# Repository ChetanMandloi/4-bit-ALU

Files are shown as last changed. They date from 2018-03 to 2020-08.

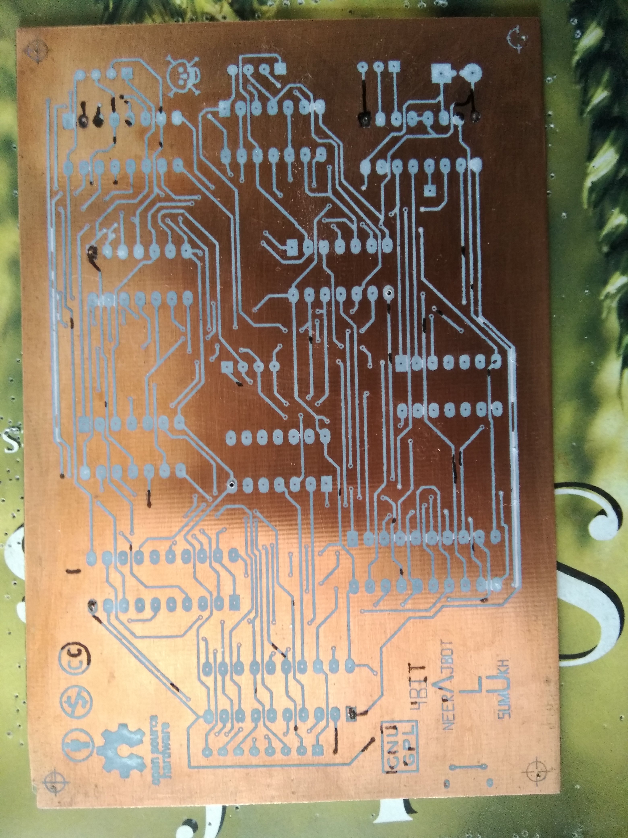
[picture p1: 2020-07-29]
Pictures of Construction/Ink Transfer on Base Module - Bottom Layer.jpg

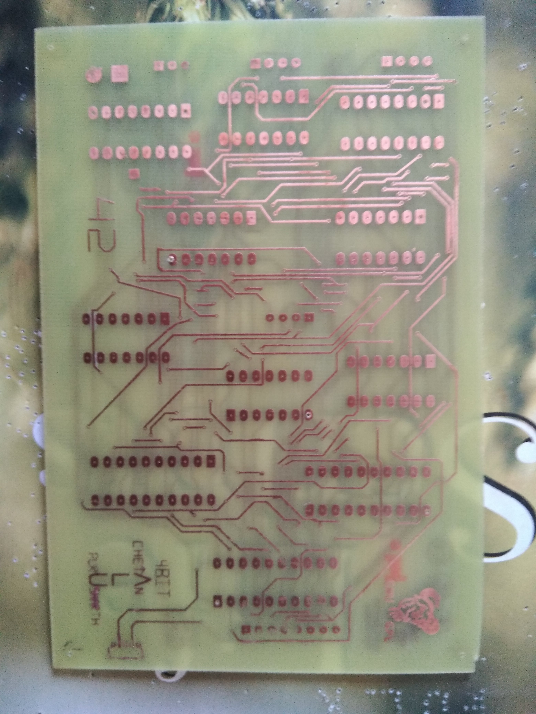
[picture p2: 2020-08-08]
Pictures of Construction/Etched Base Module - Top Layer.jpg

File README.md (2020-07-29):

# 4-bit-ALU
A simple design to perform basic logical operations (such as logical AND, OR, NOT, Addition, Subtraction and Multiplication) on two 4 bit variables using DIY PCB fabrication and assembly methods.

KiCad files to allow you to make a 4 bit ALU using Double sided copper clad board.
Pictures and instructions incoming soon.

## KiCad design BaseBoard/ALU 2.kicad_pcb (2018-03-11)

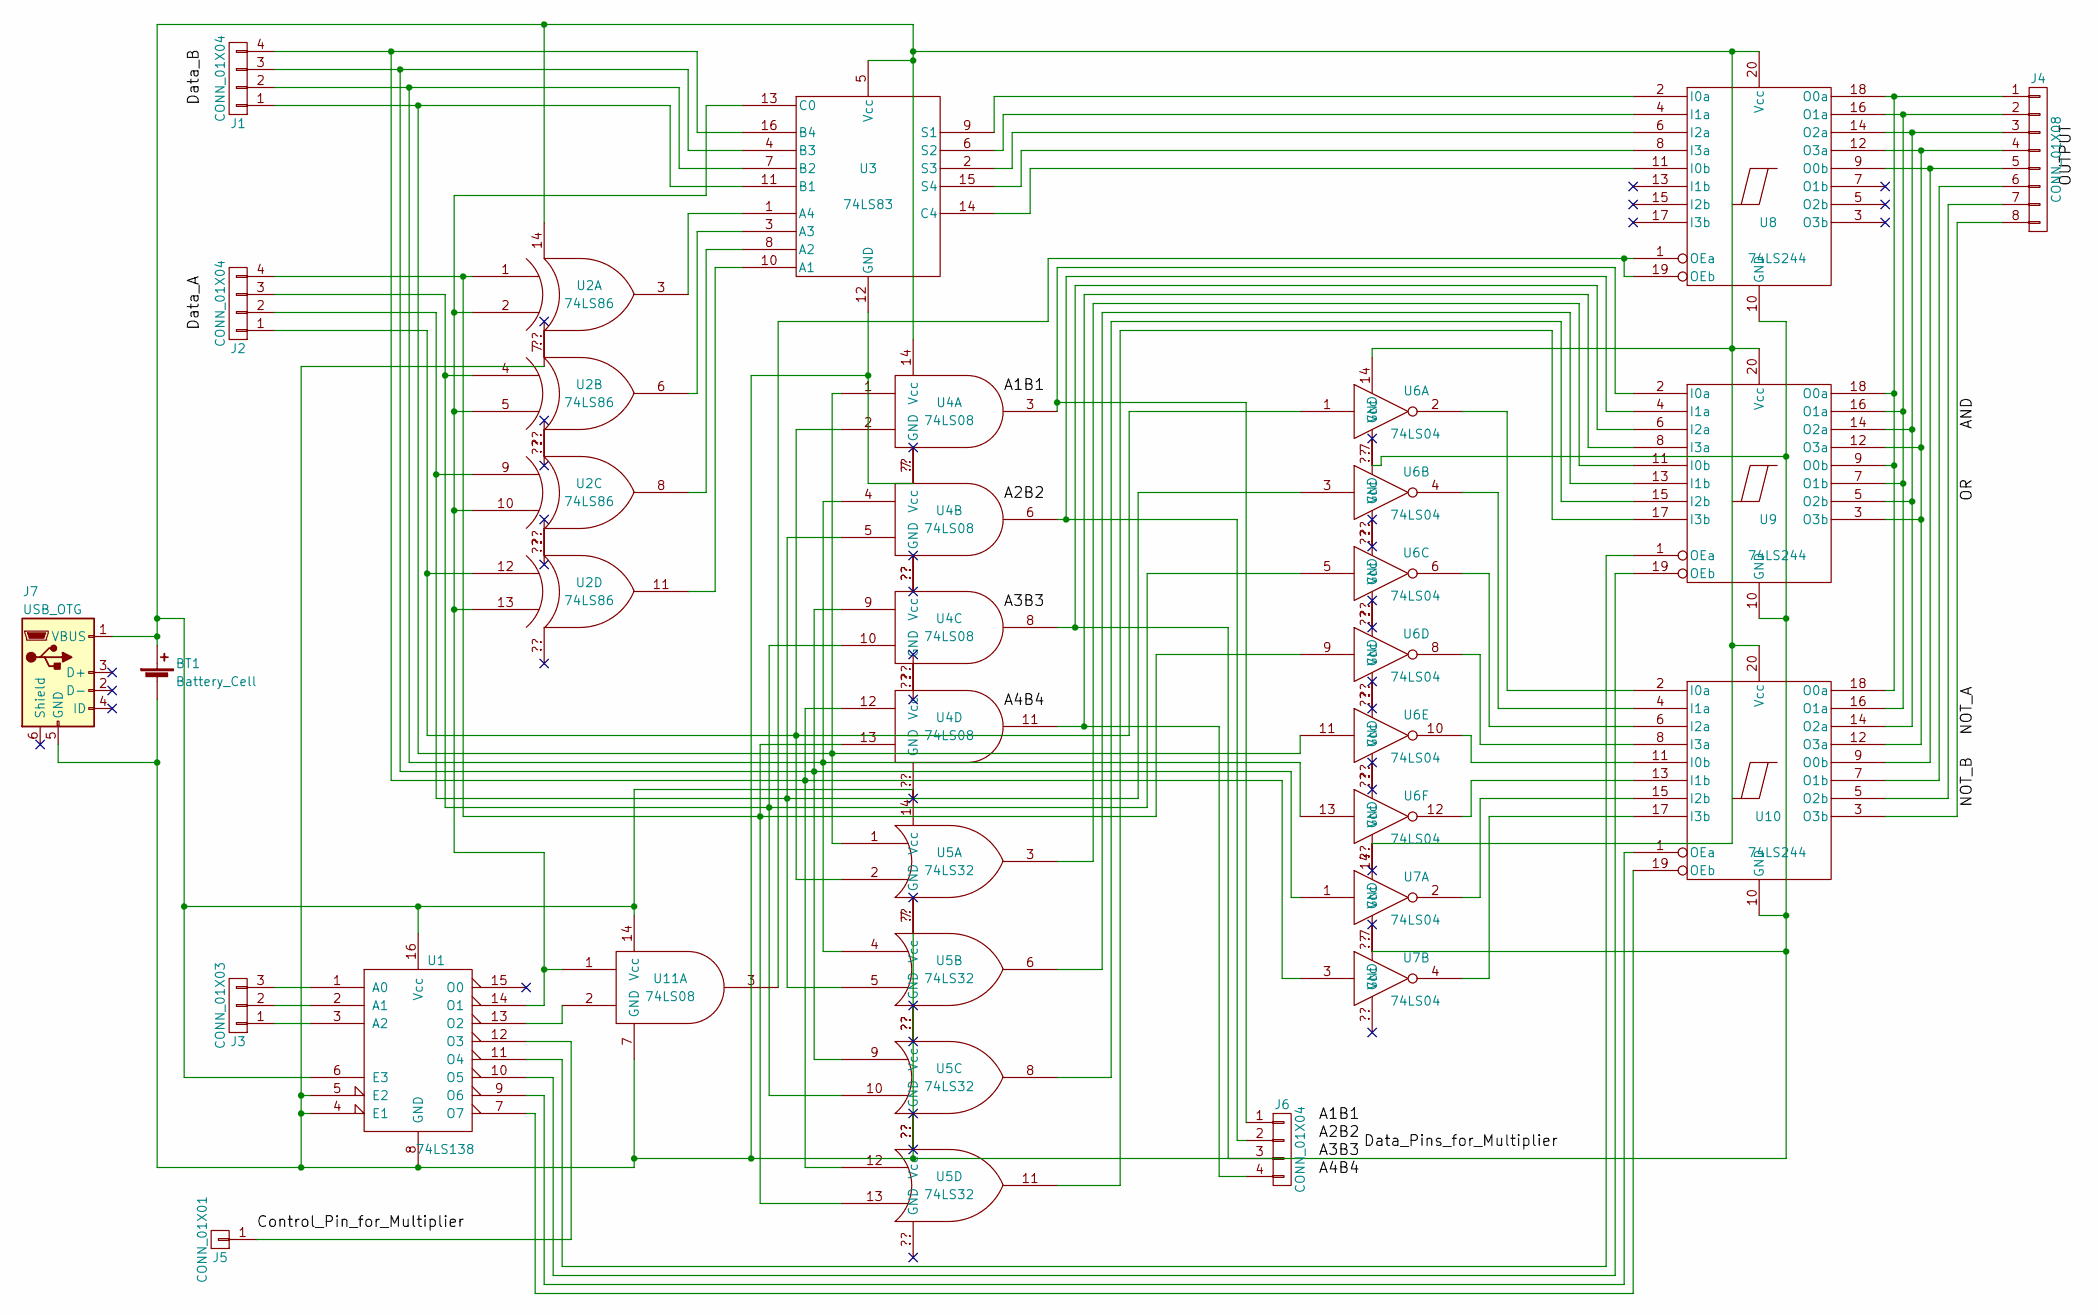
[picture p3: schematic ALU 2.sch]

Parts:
BT1: Battery_Cell; bornier2
J1, J2, J6: CONN_01X04; Pin_Header_Straight_1x04_Pitch2.54mm
J3: CONN_01X03; Pin_Header_Straight_1x03_Pitch2.54mm
J4: CONN_01X08; Pin_Header_Straight_1x08_Pitch2.54mm
J5: CONN_01X01; Pin_Header_Straight_1x01_Pitch2.54mm
J7: USB_OTG; USB_Micro-B
U1: 74LS138; DIP-16_W7.62mm_Socket_LongPads
U2: 74LS86; DIP-14_W7.62mm_Socket_LongPads
U3: 74LS83; DIP-16_W7.62mm_Socket_LongPads
U4, U11: 74LS08; DIP-14_W7.62mm_Socket_LongPads
U5: 74LS32; DIP-14_W7.62mm_Socket_LongPads
U6, U7: 74LS04; DIP-14_W7.62mm_Socket_LongPads
U8, U9, U10: 74LS244; DIP-20_W7.62mm_Socket_LongPads

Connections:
/A2B2: BT1.2 (-), J7.5 (GND), U1.4 (E1), U1.5 (E2), U1.8 (GND), U2.7 (GND), U3.12 (GND), U4.7 (GND), U5.7 (GND), U6.7 (GND), U7.7 (GND), U8.10 (GND), U9.10 (GND), U10.10 (GND), U11.7 (GND)
unnamed: BT1.1 (+), J7.1 (VBUS), U1.6 (E3), U1.16 (Vcc), U2.14 (Vcc), U3.5 (Vcc), U4.14 (Vcc), U5.14 (Vcc), U6.14 (Vcc), U7.14 (Vcc), U8.20 (Vcc), U9.20 (Vcc), U10.20 (Vcc), U11.14 (Vcc)
unnamed: J1.1, U3.11 (B1), U4.1, U5.1, U6.11
unnamed: J1.2, U3.7 (B2), U4.4, U5.4, U6.13
unnamed: J1.3, U3.4 (B3), U4.9, U5.9, U7.1
unnamed: J1.4, U3.16 (B4), U4.12, U5.12, U7.3
unnamed: J2.1, U2.12 (IN1), U4.2, U5.2, U6.1
unnamed: J2.2, U2.9 (IN1), U4.5, U5.5, U6.3
unnamed: J2.3, U2.4 (IN1), U4.10, U5.10, U6.5
unnamed: J2.4, U2.1 (IN1), U4.13, U5.13, U6.9
unnamed: J3.1, U1.3 (A2)
unnamed: J3.2, U1.2 (A1)
unnamed: J3.3, U1.1 (A0)
unnamed: J4.1, U8.18 (O0a), U9.9 (O0b), U9.18 (O0a), U10.18 (O0a)
unnamed: J4.2, U8.16 (O1a), U9.7 (O1b), U9.16 (O1a), U10.16 (O1a)
unnamed: J4.3, U8.14 (O2a), U9.5 (O2b), U9.14 (O2a), U10.14 (O2a)
unnamed: J4.4, U8.12 (O3a), U9.3 (O3b), U9.12 (O3a), U10.12 (O3a)
unnamed: J4.5, U8.9 (O0b), U10.9 (O0b)
unnamed: J4.6, U10.7 (O1b)
unnamed: J4.7, U10.5 (O2b)
unnamed: J4.8, U10.3 (O3b)
unnamed: J5.1, U1.12 (O3)
unnamed: J6.1, U4.3, U9.2 (I0a)
unnamed: J6.2, U4.6, U9.4 (I1a)
unnamed: J6.3, U4.8, U9.6 (I2a)
unnamed: J6.4, U4.11, U9.8 (I3a)
unnamed: U1.7 (O7), U10.19 (OEb)
unnamed: U1.9 (O6), U10.1 (OEa)
unnamed: U1.10 (O5), U9.19 (OEb)
unnamed: U1.11 (O4), U9.1 (OEa)
unnamed: U1.13 (O2), U11.2
unnamed: U1.14 (O1), U2.2 (IN2), U2.5 (IN2), U2.10 (IN2), U2.13 (IN2), U3.13 (C0), U11.1
unnamed: U2.3 (OUT), U3.1 (A4)
unnamed: U2.6 (OUT), U3.3 (A3)
unnamed: U2.8 (OUT), U3.8 (A2)
unnamed: U2.11 (OUT), U3.10 (A1)
unnamed: U3.2 (S3), U8.6 (I2a)
unnamed: U3.6 (S2), U8.4 (I1a)
unnamed: U3.9 (S1), U8.2 (I0a)
unnamed: U3.14 (C4), U8.11 (I0b)
unnamed: U3.15 (S4), U8.8 (I3a)
unnamed: U5.3, U9.11 (I0b)
unnamed: U5.6, U9.13 (I1b)
unnamed: U5.8, U9.15 (I2b)
unnamed: U5.11, U9.17 (I3b)
unnamed: U6.2, U10.2 (I0a)
unnamed: U6.4, U10.4 (I1a)
unnamed: U6.6, U10.6 (I2a)
unnamed: U6.8, U10.8 (I3a)
unnamed: U6.10, U10.11 (I0b)
unnamed: U6.12, U10.13 (I1b)
unnamed: U7.2, U10.15 (I2b)
unnamed: U7.4, U10.17 (I3b)
unnamed: U8.1 (OEa), U8.19 (OEb), U11.3

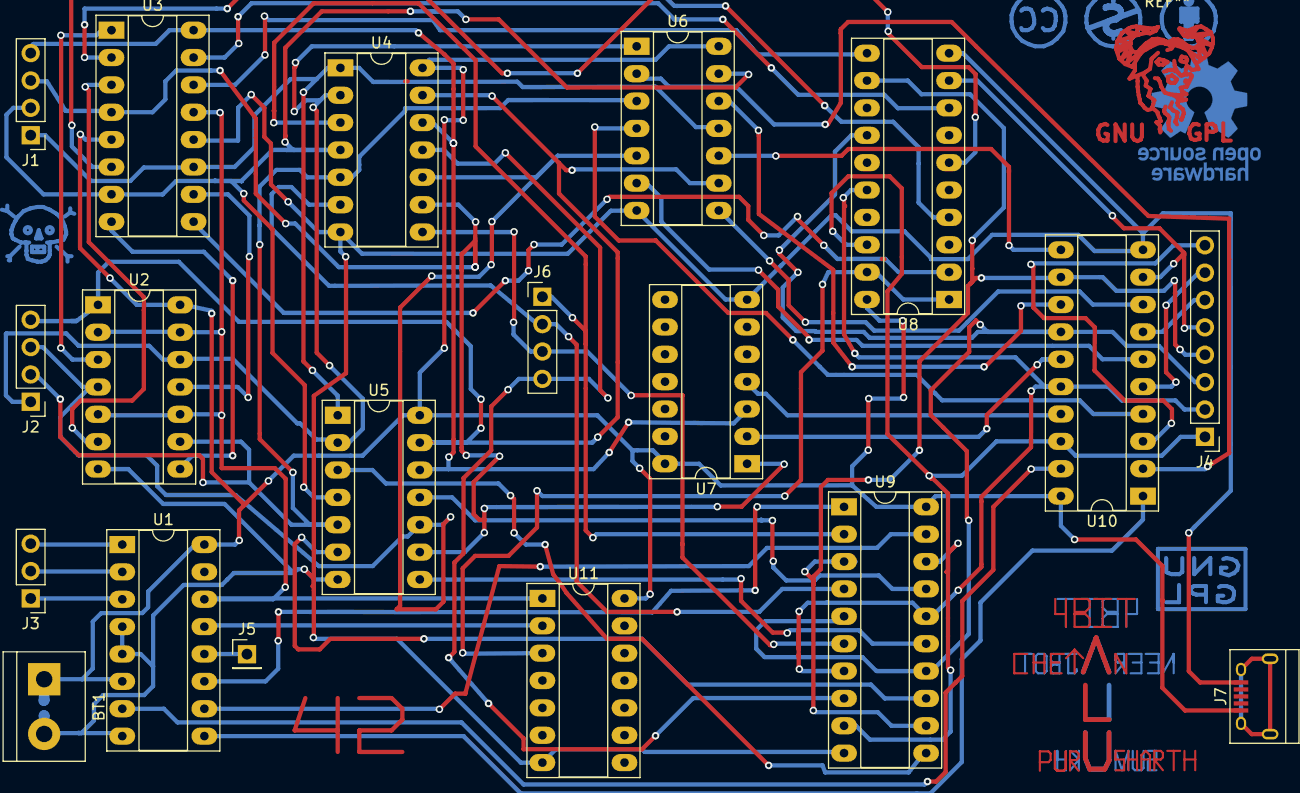
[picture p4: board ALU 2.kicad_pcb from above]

Board: 2 copper layers, 19 parts (0 on the bottom side), 54 nets.

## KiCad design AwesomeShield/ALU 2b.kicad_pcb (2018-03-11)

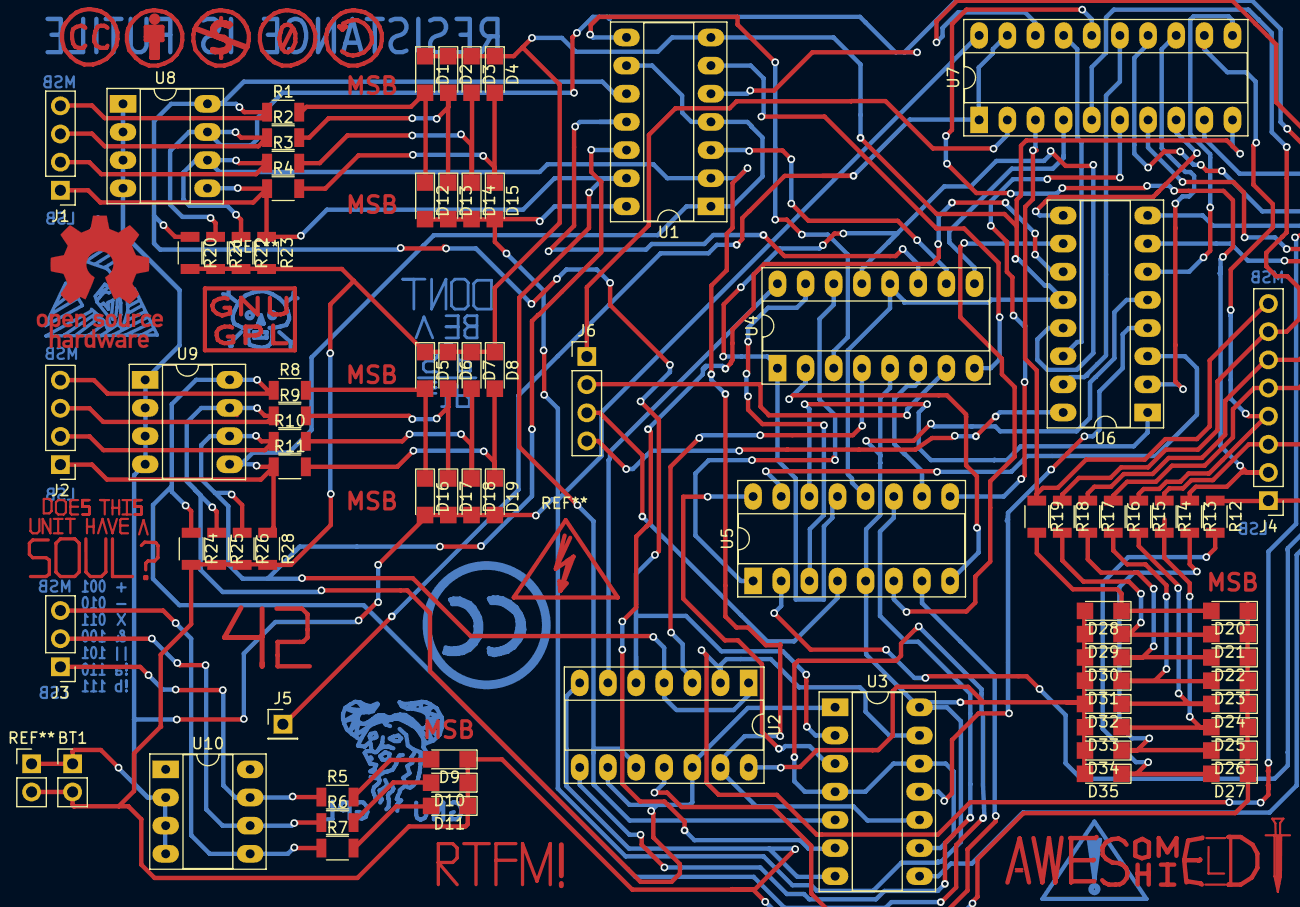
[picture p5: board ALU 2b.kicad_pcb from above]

Board: 2 copper layers, 79 parts (0 on the bottom side), 73 nets.

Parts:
BT1: Battery_Cell; Pin_Header_Straight_1x02_Pitch2.54mm
D1, D2, D3, D4, D5, D6, D7, D8, D9, D10, D11, D12, D13, D14, D15, D16, D17, D18, D19, D20, D21, D22, D23, D24, D25, D26, D27, D28, D29, D30, D31, D32, D33, D34, D35: LED; LED_1206
J1, J2, J6: CONN_01X04; Pin_Header_Straight_1x04_Pitch2.54mm
J3: CONN_01X03; Pin_Header_Straight_1x03_Pitch2.54mm
J4: CONN_01X08; Pin_Header_Straight_1x08_Pitch2.54mm
J5: CONN_01X01; Pin_Header_Straight_1x01_Pitch2.54mm
R1, R2, R3, R4, R5, R6, R7, R8, R9, R10, R11, R12, R13, R14, R15, R16, R17, R18, R19, R20, R21, R22, R23, R24, R25, R26, R28: R; R_1206
U1, U2, U3: 74LS08; DIP-14_W7.62mm_Socket_LongPads
U4, U5, U6: 74LS83; DIP-16_W7.62mm_Socket_LongPads
U7: 74LS244; DIP-20_W7.62mm_Socket_LongPads
U8, U9, U10: LM741; DIP-8_W7.62mm_Socket_LongPads

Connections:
/Control_Pin_from_Board_1: U6.15, U7.15
/Data_A: BT1.2, D1.1, D2.1, D3.1, D4.1, D5.1, D6.1, D7.1, D8.1, D9.1, D10.1, D11.1, D20.1, D21.1, D22.1, D23.1, D24.1, D25.1, D26.1, D27.1, R20.2, R21.2, R22.2, R23.2, R24.2, R25.2, R26.2, R28.2, U1.7, U2.7, U3.7, U4.12, U5.12, U6.12, U7.10
unnamed: BT1.1, D12.2, D13.2, D14.2, D15.2, D16.2, D17.2, D18.2, D19.2, D28.2, D29.2, D30.2, D31.2, D32.2, D33.2, D34.2, D35.2, U1.14, U2.14, U3.14, U4.5, U5.5, U6.5, U7.20, U8.1, U8.2, U8.3, U8.4, U9.1, U9.2, U9.3, U9.4, U10.2, U10.3, U10.4
unnamed: D1.2, D12.1, R1.2
unnamed: D9.2, R5.2
unnamed: D10.2, R6.2
unnamed: D11.2, R7.2
unnamed: D2.2, D13.1, R2.2
unnamed: D3.2, D14.1, R3.2
unnamed: D4.2, D15.1, R4.2
unnamed: D5.2, D16.1, R8.2
unnamed: D6.2, D17.1, R9.2
unnamed: D7.2, D18.1, R10.2
unnamed: D8.2, D19.1, R11.2
unnamed: D20.2, D28.1, R19.2
unnamed: D21.2, D29.1, R18.2
unnamed: D22.2, D30.1, R17.2
unnamed: D23.2, D31.1, R16.2
unnamed: D24.2, D32.1, R15.2
unnamed: D25.2, D33.1, R14.2
unnamed: D26.2, D34.1, R13.2
unnamed: D27.2, D35.1, R12.2
unnamed: J1.1, R4.1, R23.1, U1.13, U2.10, U3.5, U8.5
unnamed: J1.2, R3.1, R22.1, U1.2, U2.13, U3.10, U8.6
unnamed: J1.3, R2.1, R21.1, U1.5, U2.2, U3.13, U8.7
unnamed: J1.4, R1.1, R20.1, U1.10, U2.5, U3.2, U8.8
unnamed: J2.1, R11.1, R28.1, U1.1, U1.4, U1.9, U9.5
unnamed: J2.2, R10.1, R26.1, U1.12, U2.1, U2.4, U9.6
unnamed: J2.3, R9.1, R25.1, U2.9, U2.12, U3.1, U9.7
unnamed: J2.4, R8.1, R24.1, U3.4, U3.9, U3.12, U9.8
unnamed: J3.1, R5.1, U10.7
unnamed: J3.2, R6.1, U10.6
unnamed: J3.3, R7.1, U10.5
unnamed: J4.1, R12.1, U7.18
unnamed: J4.2, R13.1, U7.16
unnamed: J4.3, R14.1, U7.14
unnamed: J4.4, R15.1, U7.12
unnamed: J4.5, R16.1, U7.9
unnamed: J4.6, R17.1, U7.7
unnamed: J4.7, R18.1, U7.5
unnamed: J4.8, R19.1, U7.3
unnamed: J5.1, U7.1, U7.19
unnamed: J6.1, U7.2
unnamed: J6.2, U4.7
unnamed: J6.3, U5.4
unnamed: J6.4, U6.16
unnamed: U1.3, U4.10
unnamed: U1.6, U4.8
unnamed: U1.8, U4.3
unnamed: U1.11, U4.11
unnamed: U2.3, U4.4
unnamed: U2.6, U4.16
unnamed: U2.8, U5.11
unnamed: U2.11, U5.7
unnamed: U3.3, U5.16
unnamed: U3.6, U6.11
unnamed: U3.8, U6.7
unnamed: U3.11, U6.4
unnamed: U4.1, U4.13, U5.13, U6.13
unnamed: U4.2, U5.8
unnamed: U4.6, U5.10
unnamed: U4.9, U7.4
unnamed: U4.14, U5.1
unnamed: U4.15, U5.3
unnamed: U5.2, U6.8
unnamed: U5.6, U6.10
unnamed: U5.9, U7.6
unnamed: U5.14, U6.1
unnamed: U5.15, U6.3
unnamed: U6.2, U7.13
unnamed: U6.6, U7.11
unnamed: U6.9, U7.8
unnamed: U6.14, U7.17

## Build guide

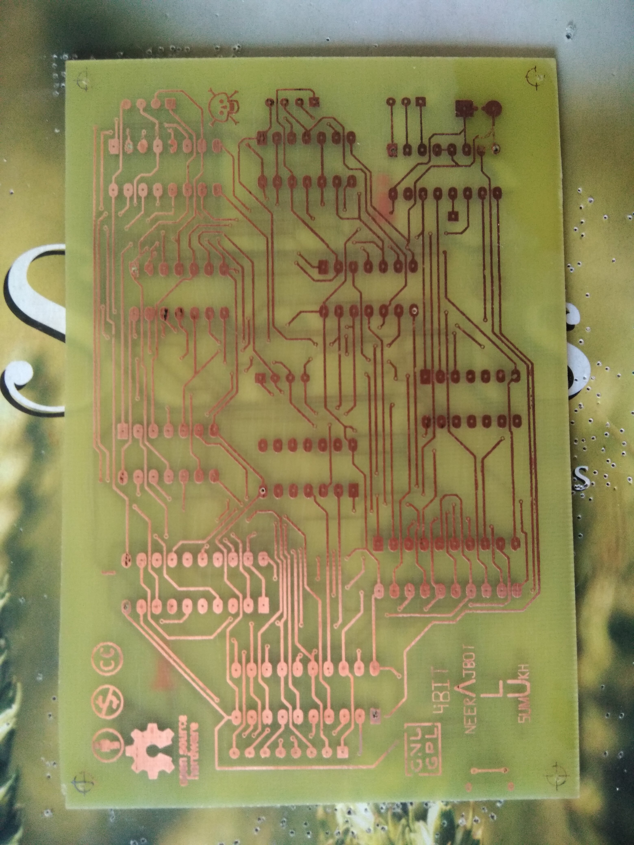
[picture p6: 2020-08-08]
Pictures of Construction/Etched Base Module - Bottom Layer.jpg

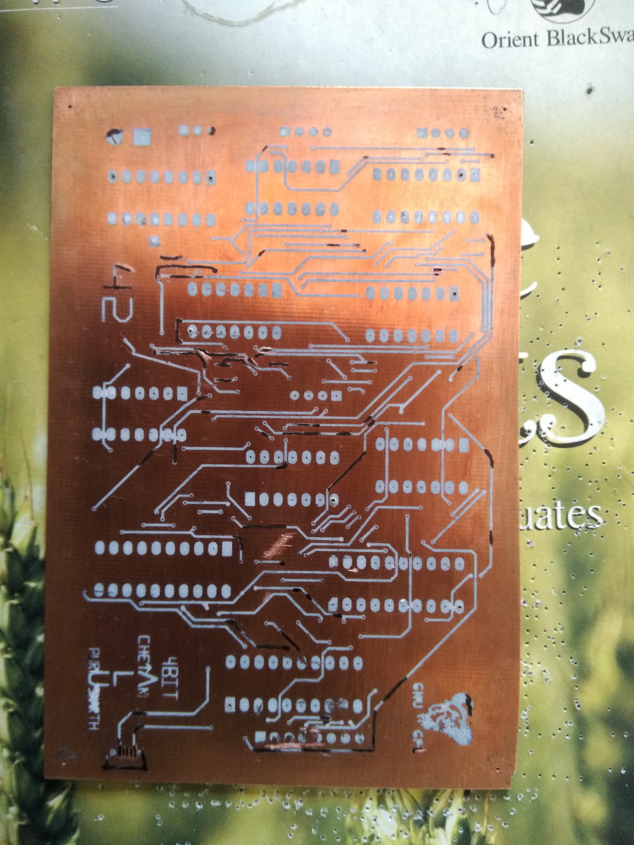
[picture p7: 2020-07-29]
Pictures of Construction/Ink Transfer on Base Module - Top Layer.jpg

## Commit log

2018-03-07 First edition
    first iteration of base
    [ALU 2.kicad_pcb, ALU 2.sch]
2018-03-07 Fixed Fab Issues Pointed out by Neeraj
    [ALU 2.kicad_pcb, ALU 2.sch]
2018-03-07 First shield iteration
    [ALU 2b.kicad_pcb, ALU 2b.sch]
2018-03-07 Added pcb file for shield
    Assigned remaining footprints and made first layout iteration
    [ALU 2b.kicad_pcb, ALU 2b.sch]
2018-03-07 Moved footprints away from the pads in layout
    [ALU 2b.kicad_pcb, ALU 2b.sch]
2018-03-07 Moved the via under the ICs
    Vias under the IC were causing short as discovered upon fabrication of the board.
    [ALU 2b.kicad_pcb, ALU 2b.sch]
2018-03-11 Final Design
    Final design of both base and shield board which is ready to roll.
    [ALU 2.kicad_pcb, ALU 2b.kicad_pcb, ALU 2b.sch]
